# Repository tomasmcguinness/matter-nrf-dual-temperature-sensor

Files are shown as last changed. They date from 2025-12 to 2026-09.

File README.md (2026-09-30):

# Nordic nRF Matter Dual Temperature Sensor

20251223_184336358_iOS

This is my Matter Dual Temperature Sensor, powered by a nRF54L15

It supports two NTC thermistor probes, allowing for two temperature readings.

It uses the standard Temperature Measurement cluster, presented on two endpoints, representing Probe 1 and Probe 2.

> [!CAUTION]
> This is designed to work as an ICD (Intermittent Connected Device), so any controller that commissions it must support the ICD mechanism.

## Battery Life

The firmware has been optimised to reduce power consumption using Matter ICD (Intermittant Connected Device) and LIT (Long Idle Time)

It consumes an average 18µA, which allows for approximately 1.5 years on a standard 240mAh 2032 coin cell battery. 

The cell voltage is reported through the standard Matter PowerSource cluster, so the remaining battery level shows up in the controller alongside the two temperatures. The coin cell drives VDD directly, so the level is read from the SAADC's internal VDD input and costs no extra hardware.

## Firmware

The code is written using the Nordic Connect SDK, v3.3.0.

### TODO

- [x] Implement ADC
- [x] Add two temperature probes
- [x] Basic indicator LED (without DK)
- [x] Press and hold to reset
- [x] User labels to name the probes
- [x] Report the battery level
- [x] Custom cluster reporting both probes from one endpoint

## Hardware

There is a PCB design, which you'll find under the firmware folder.

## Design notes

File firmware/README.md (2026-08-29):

# Firmware

## Compiling

This code has been developed against NCS v3.3.0. Note that v3.3.0 is a hard requirement: on
v3.1.0 `NRF_SAADC_VDD` resolves to the wrong SAADC input and the battery measurement reads an
external pin instead of the supply rail.

The device is battery powered only. Debug builds need no extra configuration; the `_release`
variation removes logging and the shells.

To build the custom PCB, use this command

```
west build -p -b nrf54l15dk/nrf54l15/cpuapp -- -DFILE_SUFFIX=minewsemi
```

or, for a release build

```
west build -p -b nrf54l15dk/nrf54l15/cpuapp -- -DFILE_SUFFIX=minewsemi -DEXTRA_CONF_FILE=prj_release.conf
```

To compile for the nRF54L15-DK, use this command

```
west build -p -b nrf54l15dk/nrf54l15/cpuapp
```

## Battery measurement

The coin cell drives VDD directly - there is no LDO and no divider - so the battery voltage is
read from the SAADC's internal VDD input. This costs no extra hardware and draws no quiescent
current. See `boards/nrf54l15dk_nrf54l15_cpuapp*.overlay` for the channel definition and
`src/battery.cpp` for the reader.

The voltage is sampled once shortly after start up and then once a day, and is reported through
the Matter PowerSource cluster on endpoint 0 as `BatVoltage`, `BatPercentRemaining` and
`BatChargeLevel`. The percentage is a linear mapping of the 2000mV - 3000mV CR2032 operating
window.

On the nRF54L15-DK this reads the board's VDD selector rather than a cell, which makes it
convenient for sweeping the thresholds on the bench.

## The dual temperature cluster

Alongside the two standard `TemperatureMeasurement` clusters on endpoints 1 and 2, endpoint 3
carries a manufacturer-specific cluster that reports both probes together, so a single read or
subscription returns a pair of readings taken in the same sampling pass.

| | |
|---|---|
| Cluster | `DualTemperatureMeasurement`, code `0xFFF1FC01` |
| Device type | `dual-temperature-sensor`, `0xFFF10001` |
| `Probe1MeasuredValue` | `0xFFF10000`, nullable int16s, 0.01 degC |
| `Probe2MeasuredValue` | `0xFFF10001`, nullable int16s, 0.01 degC |

The definition lives in `src/zap/DualTemperatureCluster.xml`; `src/zap/zcl.json` is the
project-local data model definition that adds it to the SDK's cluster list. The cluster has no
commands and no events, and `AppTask::SensorMeasureHandler()` writes both attributes from the
same pair of readings it gives to endpoints 1 and 2.

The high half of the cluster code is the vendor ID. This uses `0xFFF1`, the CSA test vendor,
which is also what the build falls back to because `CONFIG_CHIP_DEVICE_VENDOR_ID` is unset. That
is fine for a self-built device but is not certifiable - a real vendor ID has to be set in both
places, and the attribute IDs re-prefixed to match.

Endpoints 0, 1 and 2 are untouched, so controllers that know nothing about the custom cluster
still see the two temperature sensors and the battery exactly as before.

## Regenerating the data model

The ZAP generated sources under `src/zap/zap-generated` are checked in and consumed directly
(`BYPASS_IDL`), so editing `src/zap/template.zap` has no effect until they are regenerated.

Because the data model contains a manufacturer-specific cluster, generation has to run in
**full** mode: the app-common accessors for `DualTemperatureMeasurement` do not exist in the
SDK's prebuilt `zzz_generated/app-common`, so they are generated here instead and
`CMakeLists.txt` points `CHIP_APP_ZAP_DIR` at `src/zap/zap-generated` to override the SDK copy.
The cluster is also named in the `EXTERNAL_CLUSTERS` argument to `ncs_configure_data_model()`,
which tells the build not to look for an SDK-side server implementation.

Edit the data model in the ZAP GUI:

```
west zap-gui -j src/zap/zcl.json
```

Then regenerate:

```
export PATH=$HOME/ncs/toolchains/43683a87ea/usr/local/lib/python3.12/site-packages/clang_format/data/bin:$PATH
west zap-generate --full
```

`--full` clears and rewrites the whole of `src/zap/zap-generated` (including the `app-common`,
`clusters` and `devices` subtrees) and regenerates `src/zap/template.matter`.

If the cluster XML is ever renamed or a second custom cluster is added, regenerate `zcl.json`
first:

```
west zap-append -o src/zap/zcl.json --clusters src/zap/DualTemperatureCluster.xml
```

Three notes on the environment:

- Both commands need a west workspace. Run them from inside the NCS toolchain
  (`nrfutil sdk-manager toolchain launch --shell --ncs-version v3.3.0`) with
  `ZEPHYR_BASE=$HOME/ncs/v3.3.0/zephyr` exported, otherwise west cannot find its extension
  commands.
- The templates must come from the **v3.3.0** SDK. v3.3.0's `chip_data_model.cmake` expects
  `CodeDrivenInitShutdown.cpp` and `CodeDrivenCallback.h` in the generated directory, and the
  older templates do not emit them, so the build fails at the configure step.
- `clang-format` must be on the PATH or the generator skips prettifying and the output differs
  from the checked-in files by formatting alone. The version above (17.0.1, from the v3.2.0
  toolchain) is the one that matches the existing files - the v3.3.0 toolchain ships 21.1.8,
  which formats slightly differently.

`src/zap/zcl.json` and `src/zap/template.zap` both hold paths into the SDK that are relative to
this checkout, so they assume the NCS workspace sits at `~/ncs/v3.3.0`.

## Flashing

To flash the firmware, run the following command

```
west flash
```

If the device has protected firmware, like the MinewSemi ME54BS01, you may need to use the
recover flag

```
west flash --recover
```

> [!NOTE]
> Ultimately, the use of protected firmware will be restored. I can only learn some many things at once!

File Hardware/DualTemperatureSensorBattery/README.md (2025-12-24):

# Bill of Materials (BOM)

This page is just a scratch pad as I try to figure out the bill of materials.

LDO
MCP1700T-2202E/TT

Push Button
TS04-66-48-BK-100-SMT

Connectors
S2B-PH-SM4-TB

LED
HSMH-H170

Capacitors
C0805Y104K1RACAUTO

Resistors
AR0805FR-07330RL
RNCE0805BTE10K0

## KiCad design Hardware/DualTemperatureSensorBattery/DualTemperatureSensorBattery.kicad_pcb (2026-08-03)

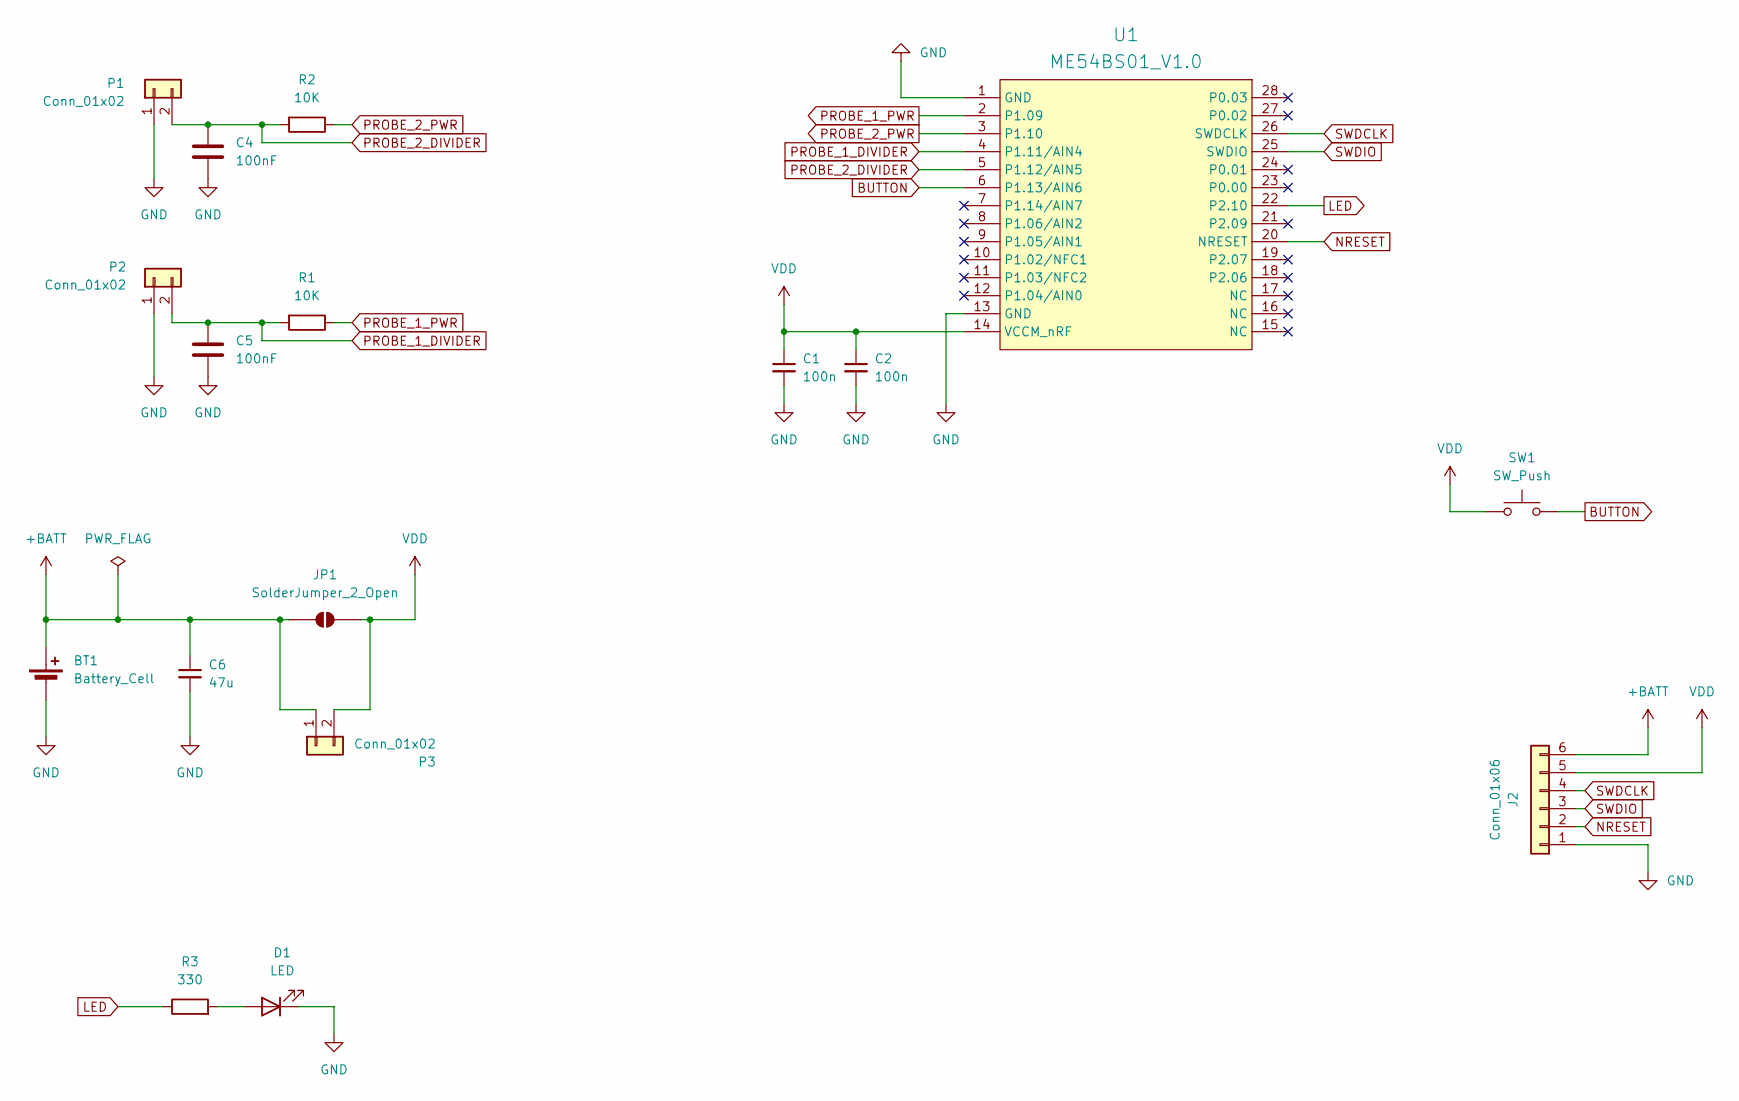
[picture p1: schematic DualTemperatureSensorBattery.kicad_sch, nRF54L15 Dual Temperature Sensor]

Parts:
BT1: Battery_Cell; BatteryHolder_Keystone_3034_1x20mm
C1, C2: 100n; C_0805_2012Metric; mouser# 581-04025C104KAT4A
C4, C5: 100nF; C_0805_2012Metric
C6: 47u; C_0805_2012Metric; mouser# 581-04025C104KAT4A
D1: LED; LED_0805_2012Metric
J2: Conn_01x06; PinHeader_1x06_P2.54mm_Vertical
JP1: SolderJumper_2_Open; SolderJumper-2_P1.3mm_Open_RoundedPad1.0x1.5mm
P1, P2: Conn_01x02; JST_PH_B2B-PH-SM4-TB_1x02-1MP_P2.00mm_Vertical
P3: Conn_01x02; PinSocket_2x01_P2.54mm_Vertical
R1: 10K; R_0805_2012Metric
R2: 10K; R_0805_2012Metric_Pad1.20x1.40mm_HandSolder
R3: 330; R_0805_2012Metric
SW1: SW_Push; SW_SPST_TS-1088-xR025
U1: ME54BS01_V1.0

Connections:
+BATT: BT1.1 (+), C6.1, J2.6, JP1.1 (A), P3.1
BUTTON: SW1.2, U1.6 (P1.13/AIN6)
GND: BT1.2 (-), C1.2, C2.2, C4.2, C5.2, C6.2, D1.1 (K), J2.1, P1.1, P2.1, U1.1 (GND), U1.13 (GND)
LED: R3.1, U1.22 (P2.10)
NRESET: J2.2, U1.20 (NRESET)
unnamed: D1.2 (A), R3.2
PROBE_1_DIVIDER: C5.1, P2.2, R1.2, U1.4 (P1.11/AIN4)
PROBE_1_PWR: R1.1, U1.2 (P1.09)
PROBE_2_DIVIDER: C4.1, P1.2, R2.2, U1.5 (P1.12/AIN5)
PROBE_2_PWR: R2.1, U1.3 (P1.10)
SWDCLK: J2.4, U1.26 (SWDCLK)
SWDIO: J2.3, U1.25 (SWDIO)
VDD: C1.1, C2.1, J2.5, JP1.2 (B), P3.2, SW1.1, U1.14 (VCCM_nRF)

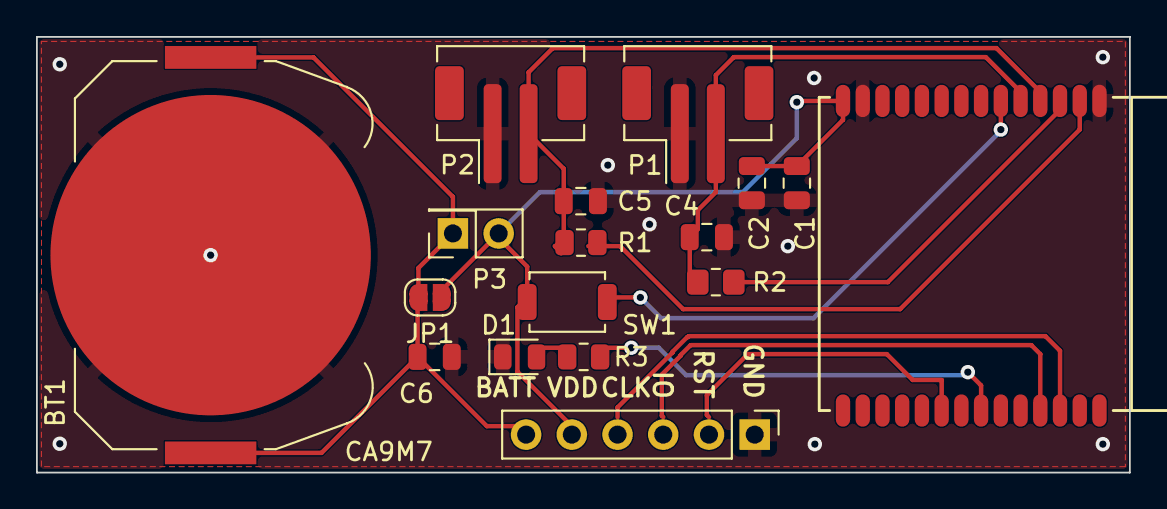
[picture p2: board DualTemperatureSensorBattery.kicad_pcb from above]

Board: 2 copper layers, 60.7 x 24.2 mm, 17 parts (0 on the bottom side), 13 nets.

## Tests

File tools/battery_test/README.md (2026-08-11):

# Battery Measurement Test Firmware

A bench-test application used to prove out battery measurement on the nRF54L15 before the code
goes into the shipping firmware under `firmware/`. It is not a product build - there is no
temperature sensing.

What it does:

- Reads the supply voltage over the SAADC every 5 seconds.
- Publishes it through the Matter Power Source cluster on endpoint 0
  (`BatVoltage`, `BatPercentRemaining`, `BatChargeLevel`, `BatPresent`).
- Blinks the indicator LED through the pairing and commissioning states.
- Lights the LED while the button is held, triggers ICD `UserActiveMode` on press, and factory
  resets when held for 10 seconds.

## Hardware

| Function | MinewSemi ME54BS01 | nRF54L15 DK |
|---|---|---|
| Indicator LED | P2.10, active high | P2.09, active high |
| Button | P1.13, active high, pull-down | P1.13, active low, pull-up |
| Battery sense | SAADC internal VDD input | SAADC internal VDD input |

The coin cell drives VDD directly - there is no LDO and no divider - so the SAADC internal VDD
input reads the cell voltage with no extra components and no quiescent draw.

The nRF54L internal reference is 900 mV and the channel uses gain 1/4, putting full scale at
3.6 V. Note that nRF54L15 has no 1/6 gain (only 2, 1, 2/3, 2/4, 2/5, 2/6, 2/7 and 2/8), so
`ADC_GAIN_1_6` fails channel setup with `-EINVAL`.

## Compiling

Requires **NCS v3.3.0**. `NRF_SAADC_VDD` resolves to the wrong SAADC input on v3.1.0, where the
value is 9 (an external AIN) rather than the 128 the nrfx internal-VDD selector expects.

For the custom MinewSemi PCB:

```
west build -p -b nrf54l15dk/nrf54l15/cpuapp -- -DFILE_SUFFIX=minewsemi
```

For the nRF54L15 DK:

```
west build -p -b nrf54l15dk/nrf54l15/cpuapp
```

Unlike `firmware/`, no `EXTRA_CONF_FILE` is needed - there is only one data model, so the ZAP
path lives directly in `prj.conf`.

## Flashing

```
west flash
```

If the device has protected firmware, like the MinewSemi ME54BS01:

```
west flash --recover
```

## Logs

Logging is over SEGGER RTT. The battery voltage and percentage are logged on every measurement
cycle, so RTT is the primary bench readout.

The ME54BS01 has no UART and every UART instance is disabled in its overlay, so on that board
the console moves to RTT and the shell is switched off entirely - its only possible backend
would be RTT, and the RTT log backend already owns that channel. The DK build keeps the Matter
shell on its UART.

## Partitioning

MCUboot, the partition manager layouts and the factory data partition are all carried over
from `firmware/` unchanged, so the flash layout matches the shipping firmware. This is not
because the test app needs DFU - it does not - but because the Matter OTA requestor in the data
model and the factory data generator both require a Partition Manager layout to build at all.

## Regenerating the data model

`cmake/data_model.cmake` passes `BYPASS_IDL`, so the contents of `src/zap/zap-generated/` are
consumed as-is and the ZAP tool is never run during the build. After editing
`src/zap/template.zap`, regenerate both the IDL and the C++ by hand:

```
export ZAP_INSTALL_PATH=~/ncs/v3.3.0/modules/lib/matter/.zap-install
ZAP=~/ncs/v3.3.0/modules/lib/matter/scripts/tools/zap/generate.py

python3 $ZAP "$PWD/src/zap/template.zap" -o "$PWD/src/zap/zap-generated" \
    -m "$PWD/src/zap/template.matter"
python3 $ZAP "$PWD/src/zap/template.zap" -o "$PWD/src/zap/zap-generated" \
    -t ~/ncs/v3.3.0/modules/lib/matter/src/app/zap-templates/app-templates.json
```

The second invocation must produce eight files. Paths passed to `generate.py` must be absolute -
relative ones are resolved against the Matter SDK root, not the working directory.

`generate.py` rewrites `template.zap` in place. The first run after an SDK version bump also
applies a one-off migration pass, which on the move to v3.3.0 wanted to add an `ma_powersource`
endpoint 1 alongside the Power Source cluster on endpoint 0. That was declined - deleting the
endpoint again sticks, since the migration does not re-run once the file has been rewritten.
Diff `template.zap` and `template.matter` after any regeneration that follows an SDK bump.

## Data model

Endpoint 0 only: `ma_rootdevice` + `ma_otarequestor`, carrying Power Source and IcdManagement.
There is no application endpoint, so `Descriptor::PartsList` is empty. That is fine for
`chip-tool`, but some commercial controllers may decline to commission a node with no
application device type. If that happens, add an endpoint in the ZAP file - no code change is
needed.

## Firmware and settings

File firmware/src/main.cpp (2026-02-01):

/*
 * Copyright (c) 2021 Nordic Semiconductor ASA
 *
 * SPDX-License-Identifier: LicenseRef-Nordic-5-Clause
 */

#include "app_task.h"
#include <zephyr/pm/device.h>
#include <zephyr/logging/log.h>

LOG_MODULE_REGISTER(app, CONFIG_CHIP_APP_LOG_LEVEL);

int main()
{
	CHIP_ERROR err = AppTask::Instance().StartApp();

	LOG_ERR("Exited with code %" CHIP_ERROR_FORMAT, err.Format());
	return err == CHIP_NO_ERROR ? EXIT_SUCCESS : EXIT_FAILURE;
}

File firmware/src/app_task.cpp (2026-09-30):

/*
 * Copyright (c) 2021 Nordic Semiconductor ASA
 *
 * SPDX-License-Identifier: LicenseRef-Nordic-5-Clause
 */

#include "app_task.h"

#include "app/matter_init.h"
#include "app/task_executor.h"
#include "board/board.h"
#include "lib/core/CHIPError.h"
#include "lib/support/CodeUtils.h"

#include <setup_payload/OnboardingCodesUtil.h>

#include <zephyr/logging/log.h>

#include <zephyr/device.h>
#include <zephyr/devicetree.h>
#include <zephyr/drivers/adc.h>
#include <zephyr/drivers/gpio.h>
#include <math.h>

#include "DeviceInfoProviderImpl.h"

#include <app-common/zap-generated/callback.h>
#include <app-common/zap-generated/attributes/Accessors.h>
#include <app/clusters/identify-server/identify-server.h>
#include <app/clusters/power-source-server/power-source-server.h>

#ifdef CONFIG_CHIP_ENABLE_ICD_SUPPORT
#include <app/icd/server/ICDConfigurationData.h>
#include <app/icd/server/ICDStateObserver.h>
#include <app/server/Server.h>
#endif

#include <zephyr/drivers/hwinfo.h>
#include <zephyr/sys/poweroff.h>

LOG_MODULE_DECLARE(app, CONFIG_CHIP_APP_LOG_LEVEL);

using namespace ::chip;
using namespace ::chip::app;
using namespace ::chip::DeviceLayer;

k_timer sIndicatorTimer;
k_timer sSensorTimer;
k_timer sBatteryTimer;
k_timer sFactoryResetTimer;
k_timer sButtonDebounceTimer;

bool mIndicatorState;

// While the button is held the LED shows the button state, so the connectivity
// blink patterns must leave it alone.
//
bool sButtonPressed;

int32_t measure_battery_voltage();

#if !DT_NODE_EXISTS(DT_PATH(zephyr_user)) || !DT_NODE_HAS_PROP(DT_PATH(zephyr_user), io_channels)
#error "No suitable devicetree overlay specified"
#endif

// Read the temperature sensors every minute.
#define SENSOR_READ_INTERVAL 60000 

// A coin cell's voltage moves over months, so a daily sample is ample resolution.
// The reading taken at start up covers cell replacement, which power cycles the
// device anyway.
//
#define BATTERY_READ_INTERVAL_HOURS 24

// The button is a bare mechanical switch with no hardware debouncing, so an
// edge is only believed once the pin has been quiet for this long.
//
#define BUTTON_DEBOUNCE_MS 20

// How long the button has to be held before the factory reset fires.
//
#define FACTORY_RESET_HOLD_SECONDS 5

// How long the probe divider is left powered before it is sampled. The 100nF
// across the thermistor and a ~5k source impedance settle in well under a
// millisecond, so this is generous.
//
#define PROBE_SETTLE_MS 50

#define THERMISTORNOMINAL 10000
#define TEMPERATURENOMINAL 25
#define BCOEFFICIENT 3977
#define SERIESRESISTOR 10000

// CR2032 operating window. The nRF54L15 itself runs well below 2.0V, but a coin
// cell's usable capacity is gone by then, so that is where 0% sits.
//
constexpr uint16_t kMinOperatingVoltageMv = 2000;
constexpr uint16_t kMaxOperatingVoltageMv = 3000;
constexpr uint16_t kWarningVoltageMv = 2400;
constexpr uint16_t kCriticalVoltageMv = 2200;

// Matter reports BatPercentRemaining in half percent units, so 200 == 100%.
//
constexpr uint8_t kMaxBatteryPercentage = 200;

// The battery channel is deliberately left out of this array. It is owned by
// battery.cpp, which picks it out of zephyr,user by name.
//
static const struct adc_dt_spec adc_channels[] = {
	ADC_DT_SPEC_GET_BY_NAME(DT_PATH(zephyr_user), probe_1),
	ADC_DT_SPEC_GET_BY_NAME(DT_PATH(zephyr_user), probe_2),
	ADC_DT_SPEC_GET_BY_NAME(DT_PATH(zephyr_user), battery)
};

#define PROBE_1_DIVIDER_POWER_NODE DT_NODELABEL(probe_1_divider_power)
#define PROBE_2_DIVIDER_POWER_NODE DT_NODELABEL(probe_2_divider_power)

#define INDICATOR_LED_NODE DT_ALIAS(indicator_led)
#define RESET_BUTTON_NODE DT_ALIAS(reset_button)

static const struct gpio_dt_spec probe_1_divider_power = GPIO_DT_SPEC_GET(PROBE_1_DIVIDER_POWER_NODE, gpios);
static const struct gpio_dt_spec probe_2_divider_power = GPIO_DT_SPEC_GET(PROBE_2_DIVIDER_POWER_NODE, gpios);

static const struct gpio_dt_spec indicator_led = GPIO_DT_SPEC_GET(INDICATOR_LED_NODE, gpios);
static const struct gpio_dt_spec reset_button = GPIO_DT_SPEC_GET(RESET_BUTTON_NODE, gpios);

constexpr EndpointId kLightEndpointId = 0;
constexpr EndpointId kPowerSourceEndpointId = 0;
constexpr EndpointId kProbe1EndpointId = 1;
constexpr EndpointId kProbe2EndpointId = 2;
constexpr EndpointId kDualTemperatureEndpointId = 3;

Identify sIdentify = {kLightEndpointId, AppTask::IdentifyStartHandler, AppTask::IdentifyStopHandler, Clusters::Identify::IdentifyTypeEnum::kVisibleIndicator};

/// @brief This function is called when an identify start command is received. It will rapidly blink the indicator LED.
/// @param
void AppTask::IdentifyStartHandler(Identify *)
{
	k_timer_stop(&sIndicatorTimer);
	k_timer_start(&sIndicatorTimer, K_MSEC(500), K_MSEC(500));
}

/// @brief This function is called when an identify stop command is received. It will turn off the indicator LED.
/// @param
void AppTask::IdentifyStopHandler(Identify *)
{
	k_timer_stop(&sIndicatorTimer);
	gpio_pin_set_dt(&indicator_led, 0);
}

/// @brief This callback is called when the sensor timer expires. It will post a task to read the temperature sensors.
/// @param timer
void AppTask::SensorTimerCallback(k_timer *timer)
{
	Nrf::PostTask([]
				  { AppTask::SensorMeasureHandler(); });
}

/// @brief This callback is called when the battery timer expires. It will post a task to read the battery voltage.
/// @param timer
void AppTask::BatteryTimerCallback(k_timer *timer)
{
	Nrf::PostTask([]
				  { AppTask::BatteryMeasureHandler(); });
}

void AppTask::IndicatorTimerCallback(k_timer *timer)
{
	LOG_DBG("LED Indicator: %d", mIndicatorState);

	mIndicatorState = !mIndicatorState;

	gpio_pin_set_dt(&indicator_led, mIndicatorState);
}

void AppTask::FactoryResetTimerCallback(k_timer *timer)
{
	gpio_pin_set_dt(&indicator_led, 0);

	Nrf::PostTask([]
				  { AppTask::FactoryResetHandler(); });
}

/// @brief Runs on the app task, so it is safe to touch the CHIP stack here.
void AppTask::FactoryResetHandler()
{
	LOG_INF("Factory Reset Triggered!");

	chip::Server::GetInstance().ScheduleFactoryReset();
}

#ifdef CONFIG_CHIP_ICD_UAT_SUPPORT
/// @brief Hands the ICD wake-up to the CHIP thread.
///
/// ScheduleWork() rather than LockChipStack() on the app task: the CHIP thread
/// already holds the stack lock when it runs the work, and the app task is left
/// free to keep dispatching - a button release, or a sensor read, is not stuck
/// behind however long the ICD manager takes.
void AppTask::UserActiveModeHandler()
{
	LOG_INF("ICD UserActiveMode is enabled. Moving to ActiveMode...");

	chip::DeviceLayer::PlatformMgr().ScheduleWork([](intptr_t)
												  {
		Server::GetInstance().GetICDManager().OnNetworkActivity();

		LOG_INF("Successfully triggered ICD UserActiveMode!"); },
												  0);
}
#endif
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

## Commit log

2025-07-09 Add two temperature measurement clusters
2025-07-09 Ported the basic code over. Removed lots of unused files. Probe 1 is working. Probe 2 is untested.
2025-07-14 Power consumption with sensors off is not at 70µA
2025-07-16 Remove on/off cluster. Further tweaks to try and get power consumption down.
2025-07-18 Restore code that reads temperature via ADC
2025-08-08 Restore basic template sample
2025-08-08 Add two temperature sensor endpoints, updating with random value every 5 seconds.
2025-08-13 Add divider power pin support
2025-08-29 Add a second divider power output to improve accuracy
2025-09-01 Add WIP PCB
    [PCB.kicad_pcb, PCB.kicad_sch]
2025-09-01 Add KiCad lock file to gitignore
2025-09-02 Reset back to Template sample in NCS v3.1.0
    [app_task.cpp]
2025-09-04 Trying to reduce power consumption
2025-09-10 Switch off the LEDs in config. Restore the board init and callback.
2025-09-10 Enable ADC peripheral. Disable CHIP Shell for size.
2025-09-10 Add ADC reading code and divider power configuration
2025-09-11 Switch GPIO ports for power. Turn off Flash protection. Tweak timer delay.
2025-09-11 Configure GPIOs for power and ADC
2025-09-11 Get ADC reference voltage using API.
2025-09-13 Working on getting ADC channel 0 reading correctly.
    [app_task.cpp]
2025-09-13 More work to get single ADC channel working
2025-09-17 Work on PCB
    [PCB.kicad_sch]
2025-09-19 ADC working on AIN4 & AIN5
2025-09-19 Both power and ADC is working
2025-10-09 Add simple indicator light support. Add overlay for reset button.
2025-10-15 Comment out code to try and diagnost boot issue
    [app_task.cpp]
2025-10-16 Restore the template sample to try and fix the build issue.
    [app_task.cpp]
2025-10-16 Update template.zap with temperature clusters
2025-10-16 Remove template folder (copy/paste mistake I think)
    [app_task.cpp]
2025-10-17 Change some config for the PCB design
2025-10-17 Update PCB with new pin outs
    [PCB.kicad_pcb, PCB.kicad_sch]
2025-10-18 Update the PCB
    [PCB.kicad_pcb, PCB.kicad_sch]
2025-10-18 Another small PCB update
    [PCB.kicad_pcb]
2025-10-19 WIP Reworking schematic with Reddit feedback
    [PCB.kicad_pcb, PCB.kicad_sch]
2025-10-20 Cleaned up schematic to be all in one. Trying to get updated layout for PCB
    [PCB.kicad_pcb, PCB.kicad_sch]
2025-10-20 Another PCB update
    [PCB.kicad_pcb]
2025-10-22 PCB: Add another PIN to the header so power can be provided via J-Link.
    [PCB.kicad_pcb, PCB.kicad_sch]
2025-10-24 Move decoupling capacitors closer to LDO. Ground module PIN 1.
    [PCB.kicad_pcb, PCB.kicad_sch]
2025-10-24 Move decoupling capacitors even closer
    [PCB.kicad_pcb]
2025-10-27 Start of a README for the PCB
2025-11-18 Fix Nordic DevKit build. Use DK LED and Button configuration.
2025-11-19 Power consumption down to 100µA
2025-11-19 Bring power config into the release file. Remove unused nrf54L10 overlay.
2025-11-19 Add device configuration to the internal overlay
2025-11-20 Increase sensor reading to 30 second frequency. Turn off LOG and CONSOLE
2025-11-20 Update PCB with fix for LDO and tracing improvements.
    [PCB.kicad_pcb, PCB.kicad_sch]
2025-11-21 Fix sensor timer
2025-11-25 Small tweak of reference voltage to 2.2V
2025-11-28 Fix Reset button PIN.
2025-12-08 Revision 2 of the PCB using all SMD components
    [PCB.kicad_pcb, PCB.kicad_sch]
2025-12-15 BOM and small tweaks
2025-12-24 Commented out broken logging
    [app_task.cpp]
2025-12-31 Turn LED on for 1 second on boot. Small logging tweaks and code cleanup.
2025-12-31 KiCad Backup change
2025-12-31 Turn on LED when reset button is pressed. Add more logging
2026-01-06 Switch Reset Button from GPIO2 to GPIO1 to fix issue when MCU is asleep.
    [app_task.cpp]
2026-01-07 Add configuration for both battery and main
2026-01-07 Move some of the cmake files from the samples/common to this project to reduce dependency
2026-01-07 Update README to mark user labels task as complete
    https://tomasmcguinness.com/2026/01/07/dual-temperature-sensor-configuring-fixedlabels-in-matter/
2026-01-10 new conf files for usb/battery
2026-01-12 Add new clusters for power source
2026-01-15 Enable property ICD support in Battery configuration.
2026-01-15 Created Wired ZAP configuration
2026-02-01 Changes to reduce power consumption. 1-minute average now 18µA
2026-02-03 Enhance README with additional product details
    Expanded the README to include details about temperature probe support, battery life, and firmware version.
2026-02-14 Switch reset interrupt to GPIO_INT_EDGE_TO_ACTIVE. Restore UART for DK overlay. Make wired a Full Thread Device. Tidy up logging configuration. Turn off Thread SSED.
    [app_task.cpp]
2026-02-15 Update README with progress note and PCB design info
    Clarified the work in progress note and updated PCB design location.
2026-02-16 Starting different PCB designs for USB & Battery
    [PCB.kicad_pcb, PCB.kicad_sch]
2026-02-18 Config RTT logs. Remove SSED setting. Update readme with correct wired.conf file name.
2026-07-28 WIP Finished outline with LDO
    [PCB.kicad_pcb, PCB.kicad_sch]
2026-07-31 Rename the project. Finish routing.
    [DualTemperatureSensorBattery.kicad_pcb, DualTemperatureSensorBattery.kicad_sch]
2026-07-31 Removed original files left after rename
    [PCB.kicad_pcb, PCB.kicad_sch]
2026-08-03 Removed the battery measurement. Reworked some of the layout.
    [DualTemperatureSensorBattery.kicad_pcb, DualTemperatureSensorBattery.kicad_sch]
2026-08-11 Rename folder to lower case firmware
2026-08-11 Add battery_test ool. Remove Wired version. Add ADC battery measurement.
2026-08-11 Removed unneeded boards
2026-08-29 Tinkering with factory reset support
    [app_task.cpp]
2026-09-08 Changes to support Revision B of the PCB
2026-09-30 Restored the reset button behaviour (I think). Bumped ICD active time.
